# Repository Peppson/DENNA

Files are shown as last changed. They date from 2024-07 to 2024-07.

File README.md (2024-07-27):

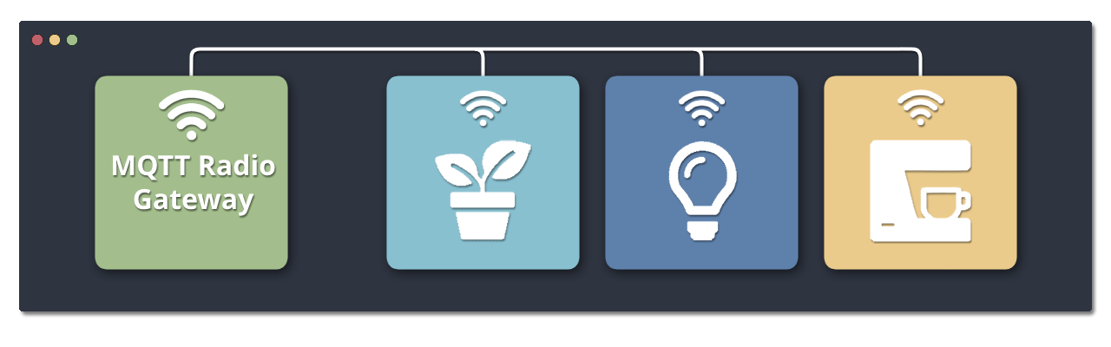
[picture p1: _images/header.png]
flow_diagram


# radio-nodes

Solar/Battery/USB powered wireless "smarthome" modules, based on the Attiny824 microcontroller.  
Serves as the end-node of [MQTT-radio-gateway](https://github.com/Peppson/MQTT-radio-gateway).   
Written in C++ with PlatformIO.  

&nbsp;
## Project Overview
- Each node is easily configurable to perform various tasks, such as watering plants,  
turn on the coffeemaker, opening blinds, relaying sensor data, etc. 

- Power consumption was the main concern when designing this.   
Nodes consumes ∼`2mA` @ 3.3V in active listening mode, and as low as ∼`3uA` @ 3.3V while deepsleeping!  
Making it possible to power some nodes indefinitely from a small solarpanel.  
Measured and optimized using [Power Profiler Kit II](https://www.nordicsemi.com/Products/Development-hardware/Power-Profiler-Kit-2).  

- This project was primarily made for personal ***"needs"***. But it is open for use by anyone who finds it beneficial.  
Every ***node*** has it's own directory inside `src` with it's own enviroment, selected from `platformio.ini`.

&nbsp;
## Hardware and PCB  
Made a compact PCB integrating a [TP4056](https://www.amazon.com/TP4056/s?k=TP4056) Li-ion/LiPo battery charger, an [nRF24L01+](https://www.amazon.com/s?k=nRF24L01%2B&crid=1VM0GXMUG7ISX&sprefix=nrf24l01%2B%2Caps%2C145&ref=nb_sb_noss_1) radio,   
and the [Attiny824](https://www.mouser.se/ProductDetail/Microchip-Technology/ATTINY824-SSF?qs=pUKx8fyJudA6%2F%2FVSNIlI1w%3D%3D) AVR microcontroller.  

More images in: [📂 _images/](./_images/)  
KiCad files: [📂 _KiCad/](./_KiCad/)  

<details>
<summary>
    Schematic
</summary>  

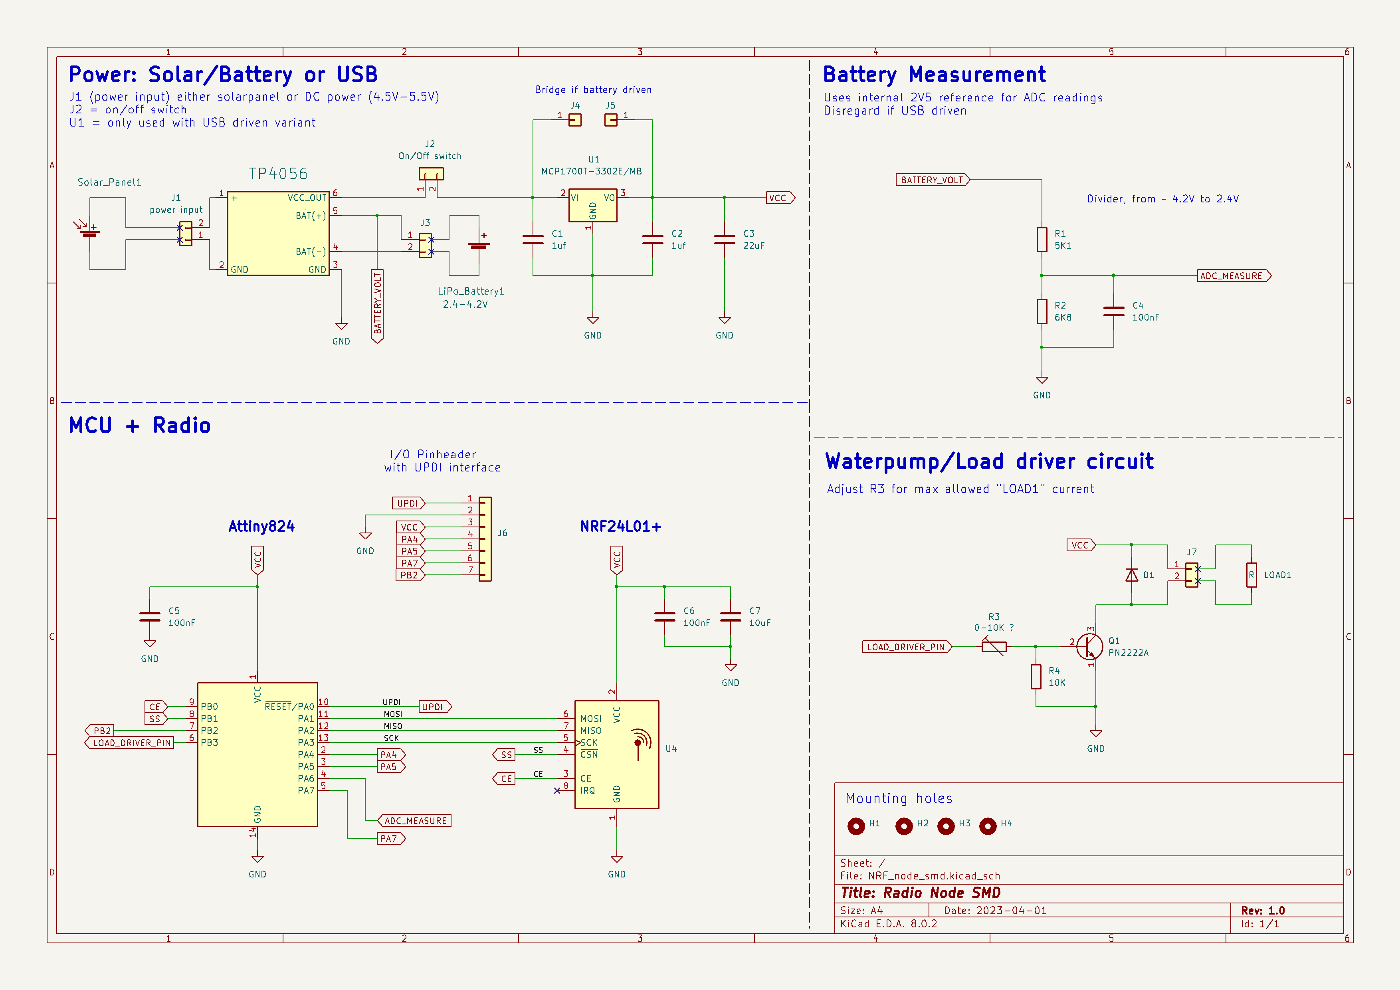
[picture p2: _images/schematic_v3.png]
schematic
  
</details>

<details>
<summary>
    PCB layout 
</summary>     
    
> 2-layer PCB, dimensions 42mm x 31mm.  
> The PCB has 3 sections, configurable based on the node.
> - ***BAT or USB:*** Battery or USB/5V driven.  
> - ***LOAD:*** Components for the "load driver circuit".  

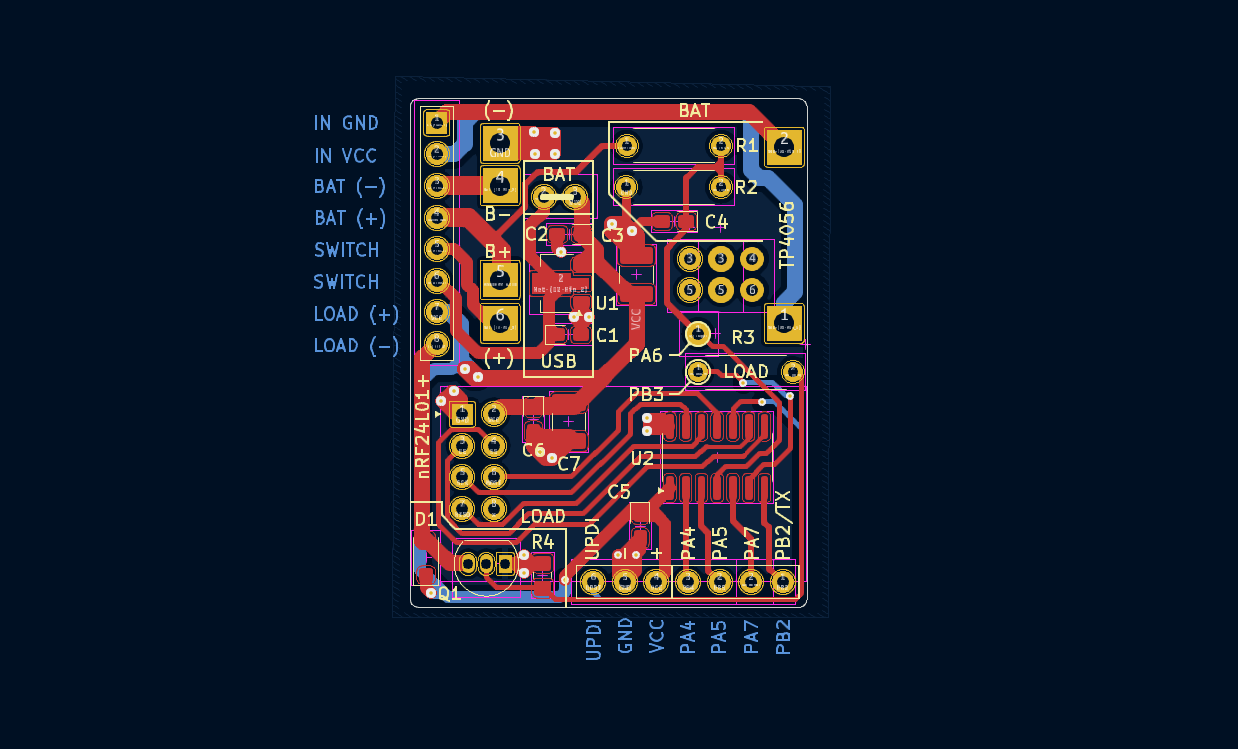
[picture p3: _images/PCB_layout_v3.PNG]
PCB_layout
  
</details>  

<details>
<summary>
    Power consumption in active mode 
</summary>  

> In active mode, the node toggles its radio `on` for 50ms and `off` for 950ms to minimize power usage,    
> halting the CPU between pulses.  
>
> Resulting in an average power draw of ∼2mA @ 3.3V.  

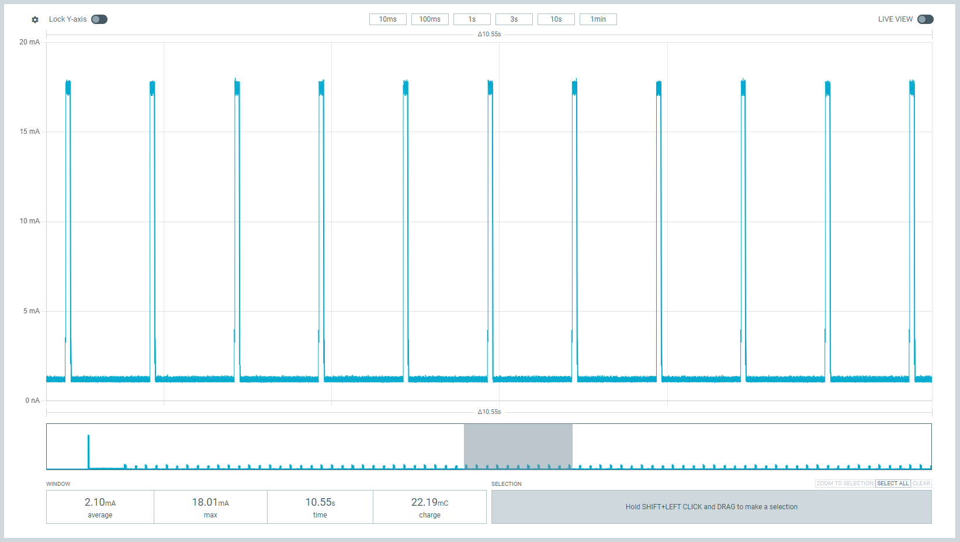
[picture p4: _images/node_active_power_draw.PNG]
  
</details>

<details>
<summary>
    Programming
</summary>  

The ATtiny 2-series MCUs have [UPDI](https://onlinedocs.microchip.com/pr/GUID-F626284A-58F0-4C25-A6F3-0EA5054F3E2B-en-US-6/index.html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) interface. Which makes it possible to program with only 1 data pin!  
You can see the UPDI pins at the bottom of the PCB. 

I created a simple DIY programmer using an Arduino Nano, to help with uploading firmware.   
More details here [UPDI programmer](https://github.com/Peppson/simple-UPDI-programmer).
</details>

### PCB
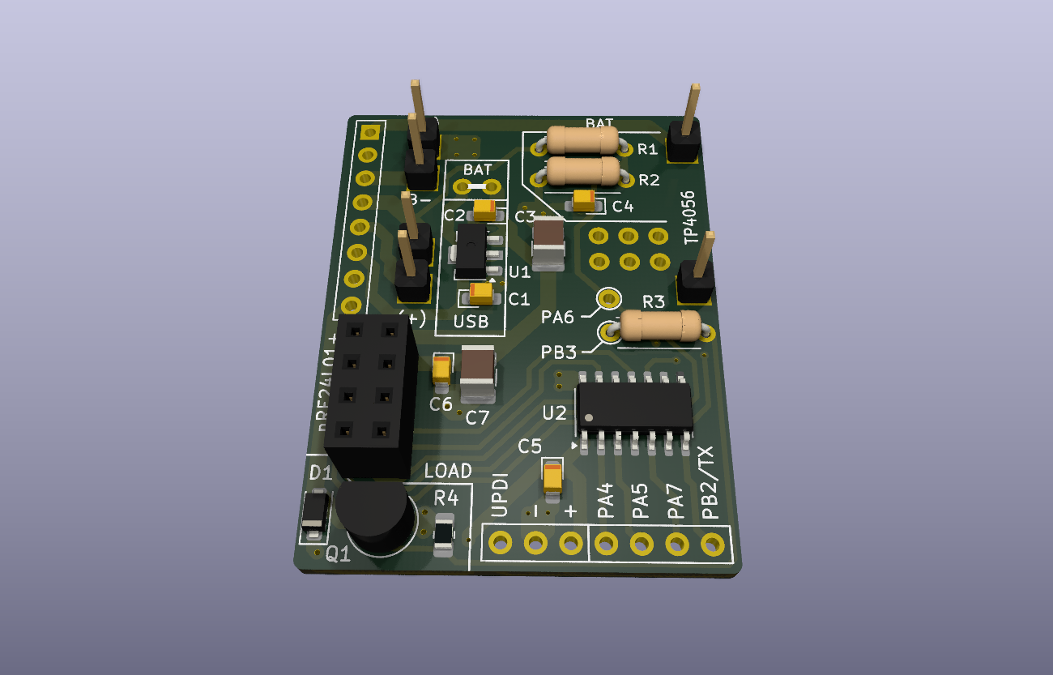
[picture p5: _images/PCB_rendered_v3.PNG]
hardware
    

### Hardware
> With and without the TP4056 and nRF24L01+ modules. Dimensions 42mm x 31mm.  
> The picture shows a battery/solar-powered node.

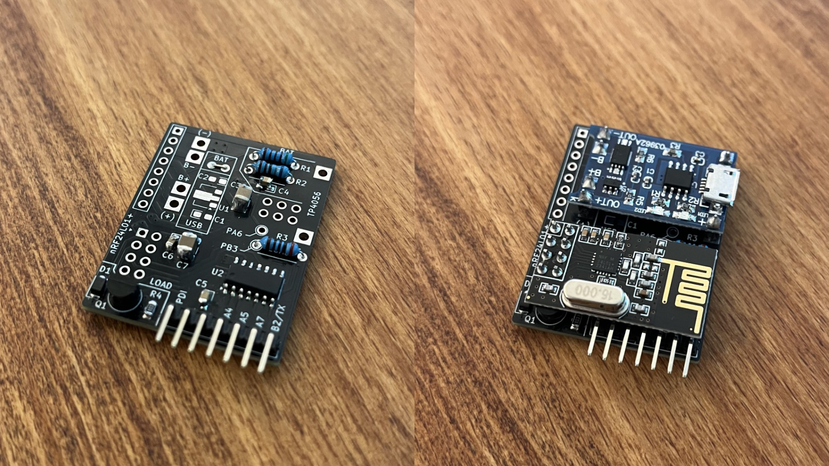
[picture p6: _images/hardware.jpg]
  

&nbsp;
## Nodes 
<details open>
<summary>
    Nodes 1-10: Self watering plants  
</summary>

Uses a 3-5V waterpump and DIY capacative fluid-level sensor.  See link below.  
[Liquid Level Sensing Using Capacitive-to-Digital Converters](https://www.analog.com/en/analog-dialogue/articles/liquid-level-sensing-using-cdcs.html)  

The solar-powered variant uses the TP4056 to charge a Li-ion/LiPo battery.  
While the USB variant skips that step and plugs directly into 5V (with 3.3V LDO onboard).  

#### Node 1 water sensor linearity:    

> Sensor (ADC) reading vs water level in %. 

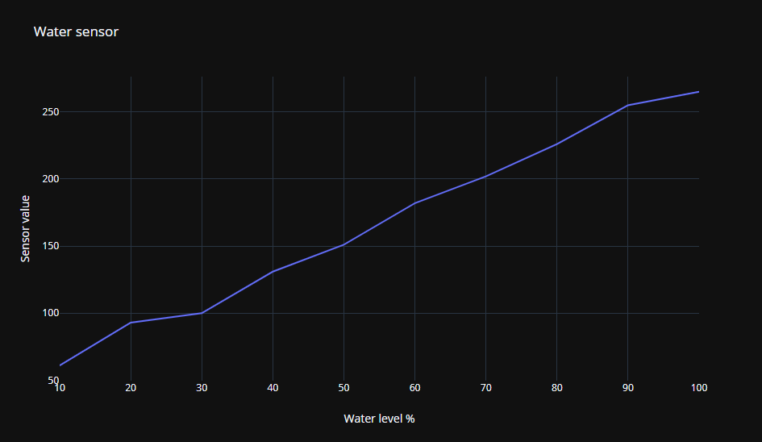
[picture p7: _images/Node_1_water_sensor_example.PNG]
water sensor


#### Node 1 hardware:  

> Most of the self-watering plant nodes have the hardware inside a plastic enclosure,   
> which I just hide behind the pots.  
> However, for node 1, I placed all electronics underneath for a pretty decent look.   

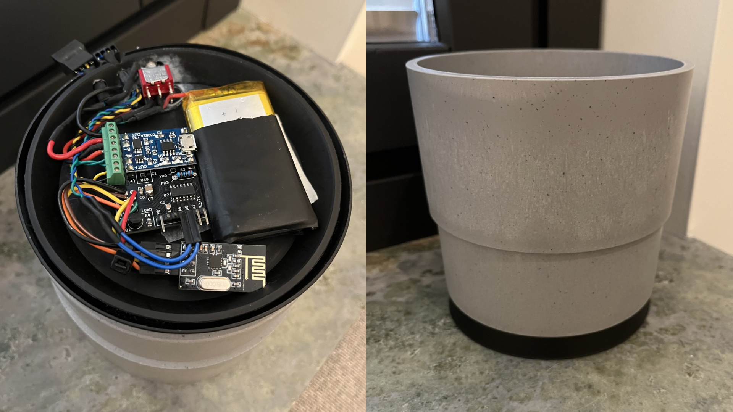
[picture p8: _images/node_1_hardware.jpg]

&nbsp;  

</details>

<details>
    <summary>
        Node 11: Mocca Master controller
    </summary>

Uses a SG90 servo mounted internally to toggle the `On/Off` button,   
and a hall-effect current sensor, to get the current state.
  
> "Looks pretty neat when the button toggles all by itself :)"   

</details>

&nbsp;

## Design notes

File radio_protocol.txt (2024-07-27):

----- Self Watering Flowerpots [1-10] -----
RX: 
    - from_who          = From who
    - to_who            = To who
    - state             = Run waterpump? 
    - data_0            = Run waterpump for how long
    - data_1            = Unused
    - data_2            = 0xFFFD = deepsleep | 0xFFFE = resend message | 0xFFFF = reboot | Current time (hhmm)
TX:
    - from_who          = From who
    - to_who            = To who
    - state             = Unused 
    - data_0            = Water level
    - data_1            = Battery charge (if battery driven)
    - data_2            = Unused / 0xFFFF = request current time

----- MoccaMaster [11] -----
RX: 
    - from_who          = From who
    - to_who            = To who
    - state             = Turn on coffeemachine? 
    - data_0            = Unused
    - data_1            = Unused
    - data_2            = 0xFFFD = deepsleep | 0xFFFE = resend message | 0xFFFF = reboot | Current time (hhmm)
TX:
    - from_who          = From who
    - to_who            = To who
    - state             = Current state of coffemachine 
    - data_0            = Number of coffees made (EEPROM)
    - data_1            = Unused
    - data_2            = Unused / 0xFFFF = request current time

...

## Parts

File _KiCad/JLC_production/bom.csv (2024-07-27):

Designator | Footprint | Quantity | Value | LCSC Part #
C1, C2 | CP_EIA-2012-15_AVX-P_Pad1.30x1.05mm_HandSolder | 2 | 1uf
C3 | 1210 | 1 | 22uF
C4, C5, C6 | CP_EIA-2012-15_AVX-P_Pad1.30x1.05mm_HandSolder | 3 | 100nF
C7 | 1210 | 1 | 10uF
D1 | D_SOD-123F | 1 | D
J6 | PinHeader_1x06_P2.54mm_Vertical | 1 | Conn_01x06
Q1 | TO-92_Inline | 1 | TO-92_Inline
R1 | R_Axial_DIN0207_L6.3mm_D2.5mm_P7.62mm_Horizontal | 1 | 5.1K
R2 | R_Axial_DIN0207_L6.3mm_D2.5mm_P7.62mm_Horizontal | 1 | 6.8K
R4 | 0805 | 1 | 10K
R8 | R_Axial_DIN0207_L6.3mm_D2.5mm_P7.62mm_Horizontal | 1 | 0-10K ?
TP4056 | TP4056-18650 | 1 | ~
U1 | SOT-89-3 | 1 | MCP1700T-3302E/MB
U2 | SOIC-14_3.9x8.7mm_P1.27mm | 1 | ATtiny84A-P
nRF24L01+ | nRF24L01_Breakout | 1 | NRF24L01_Breakout

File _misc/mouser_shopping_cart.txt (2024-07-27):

 
https://www.mouser.se/ProjectManager/ProjectDetail.aspx?AccessID=e2948668ba
Access ID: e2948668ba

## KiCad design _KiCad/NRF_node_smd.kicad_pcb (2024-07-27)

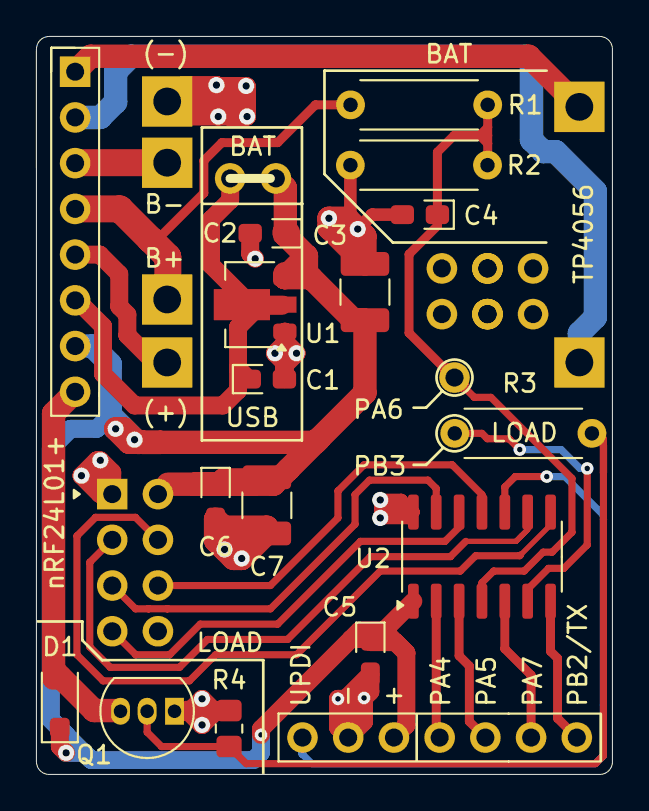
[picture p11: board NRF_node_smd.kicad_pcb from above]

Board: 2 copper layers, 32.0 x 41.0 mm, 18 parts (0 on the bottom side), 16 nets.

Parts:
C1, C2: 1uf; CP_EIA-2012-15_AVX-P_Pad1.30x1.05mm_HandSolder
C3: 22uF; C_1210_3225Metric_Pad1.33x2.70mm_HandSolder
C4, C5, C6: 100nF; CP_EIA-2012-15_AVX-P_Pad1.30x1.05mm_HandSolder
C7: 10uF; C_1210_3225Metric_Pad1.33x2.70mm_HandSolder
D1: D; D_SOD-123F
J6: Conn_01x06; PinHeader_1x06_P2.54mm_Vertical
Q1: TO-92_Inline
R1: 5.1K; R_Axial_DIN0207_L6.3mm_D2.5mm_P7.62mm_Horizontal
R2: 6.8K; R_Axial_DIN0207_L6.3mm_D2.5mm_P7.62mm_Horizontal
R4: 10K; R_0805_2012Metric_Pad1.20x1.40mm_HandSolder
R8: 0-10K ?; R_Axial_DIN0207_L6.3mm_D2.5mm_P7.62mm_Horizontal
TP4056: TP4056-18650
U1: MCP1700T-3302E/MB; SOT-89-3
U2: ATtiny84A-P; SOIC-14_3.9x8.7mm_P1.27mm
nRF24L01+: NRF24L01_Breakout; nRF24L01_Breakout

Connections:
/CE: U2.9 (PB0), nRF24L01+.3 (CE)
/MISO: U2.12 (PA2), nRF24L01+.7 (MISO)
/MOSI: U2.11 (PA1), nRF24L01+.6 (MOSI)
/SCK: U2.13 (PA3), nRF24L01+.5 (SCK)
/SS: U2.8 (PB1), nRF24L01+.4 (~CSN)
ADC_MEASURE: C4.1, R1.2, R2.2, U2.4 (PA6)
BATTERY_VOLT: R1.1, TP4056.5 (BAT(+))
GND: C1.2, C2.2, C3.2, C4.2, C5.2, C6.2, C7.2, J6.5, Q1.1, R2.1, R4.2, TP4056.3 (GND), U1.1 (GND), U2.14 (GND), nRF24L01+.1 (GND)
LOAD_DRIVER_PIN: R8.1, U2.6 (PB3)
unnamed: D1.2 (A), Q1.3
unnamed: C1.1, U1.2 (VI)
unnamed: Q1.2, R4.1, R8.2
PB4: J6.3, U2.2 (PA4)
PB5: J6.2, U2.3 (PA5)
UPDI: J6.6, U2.10 (~RESET/PA0)
VCC: C2.1, C3.1, C5.1, C6.1, C7.1, D1.1 (K), J6.4, U1.3 (VO), U2.1 (VCC), nRF24L01+.2 (VCC)

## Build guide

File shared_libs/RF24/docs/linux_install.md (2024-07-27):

# Linux Installation

@tableofcontents

<!-- markdownlint-disable MD031 -->
Generic Linux devices are supported via SPIDEV, MRAA, RPi native via BCM2835, or using LittleWire.

@note The SPIDEV option should work with most Linux systems supporting spi userspace device.

@warning These install instructions are beginning to age because they were designed with the assumption that
the arm-linux-gnueabihf-g\*\* compilers were available and default for the system. If you have problems
using the manual install instructions (especially on a 64-bit OS), please try the
[instructions using CMake](md_docs_using_cmake.html).

@note Since wiringPi is no longer maintained or distributed (as of RPi OS 11 bullseye),
pigpio is now required for using the radio's IRQ pin. This applies to RPi, SPIDEV, and pigpio drivers. The MRAA driver may provide its own IRQ implementation. Remember that the RPi OS lite variant does not ship with pigpio installed.

## Automated Install

**Designed & Tested on RPi** - Defaults to SPIDEV on devices supporting it

1. Install prerequisites if there are any (pigpio, MRAA, LittleWire libraries, setup SPI device etc)
2. Download the install.sh file from [http://tmrh20.github.io/RF24Installer/RPi/install.sh](http://tmrh20.github.io/RF24Installer/RPi/install.sh)
   ```shell
   wget http://tmrh20.github.io/RF24Installer/RPi/install.sh
   ```
3. Make it executable
   ```shell
   chmod +x install.sh
   ```
4. Run it and choose your options
   ```shell
   ./install.sh
   ```
5. Run an example from one of the libraries
   ```shell
   cd rf24libs/RF24/examples_linux
   ```
   Edit the gettingstarted example, to set your pin configuration
   ```shell
   nano gettingstarted.cpp
   make
   sudo ./gettingstarted
   ```

## Manual Install

1. Install prerequisites if there are any (pigpio, MRAA, LittleWire libraries, setup SPI device etc)
   @note See the [MRAA](http://iotdk.intel.com/docs/master/mraa/index.html) documentation for more info on installing MRAA
2. Make a directory to contain the RF24 and possibly RF24Network lib and enter it
   ```shell
   mkdir ~/rf24libs
   cd ~/rf24libs
   ```
3. Clone the RF24 repo
   ```shell
   git clone https://github.com/tmrh20/RF24.git RF24
   ```
4. Change to the new RF24 directory
   ```shell
   cd RF24
   ```
5. Configure build environment using
   ```shell
   ./configure
   ```
   script. It auto detectes device and build environment.

   For overriding autodetections, use command-line switches, see
   ```shell
   ./configure --help
   ```
   for description.
6. Build the library, and run an example file
   ```shell
   make
   sudo make install
   ```
   ```shell
   cd examples_linux
   ```
   Edit the gettingstarted example, to set your pin configuration
   ```shell
   ano gettingstarted.cpp
   make
   sudo ./gettingstarted
   ```

### Build using SPIDEV

1. Make sure that spi device support is enabled and /dev/spidev\<a\>.\<b\> is present
2. Manual Install using SPIDEV:
   ```shell
   ./configure --driver=SPIDEV
   make
   sudo make install
   ```
3. See the gettingstarted example for an example of pin configuration

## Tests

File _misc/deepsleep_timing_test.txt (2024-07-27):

15 min 
18:53:49.706 > start
19:08:49.817 > stop

2h
19:22:44.489 > start
21:22:48.503 > stop

12h TODO

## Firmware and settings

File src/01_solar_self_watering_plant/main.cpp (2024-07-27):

#include "../global_config.h"
#include "node_program.h"
#include "rf24_radio.h"
#include "hardware.h"
#include "water_system.h"
#include "utility.h"

Hardware hardware(true);
RF24Radio radio;
WaterSystem water_system(selected_node::WATER_SENSOR_MIN_VALUE, selected_node::WATER_SENSOR_MAX_VALUE);


#if CALIBRATION
void setup() { Hardware::begin(&radio); util::calibration(); }
void loop() {}
#else


void setup() {
    hardware.begin(&radio, true);
    radio.begin();
    selected_node::send_sensor_data(radio, true);
}


void loop() {
    WDT_FEED();

    // Save power by toggling radio transceiver on/off
    radio.power_up();

    // Listen for new radio message
    if (radio.wait_for_message(RF24_ON_TIME)) {
        selected_node::handle_RX_message(radio);
    }

    // Powerdown 
    radio.power_down();
    hardware.lightsleep(RF24_OFF_TIME);

    // Time to send data to master?
    uint32_t cur_time = millis();
    if (cur_time > hardware.next_update_time) {
        selected_node::send_sensor_data(radio, false);
    }

    // Time to sleep?
    if (cur_time > hardware.deepsleep_time) {
        hardware.deepsleep(selected_node::SLEEP_DURATION_SECONDS);
    } 
   
}
#endif   

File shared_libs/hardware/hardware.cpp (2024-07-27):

#include "hardware.h"
#include "utility.h"
#include "../shared_libs/rf24_radio/rf24_radio.h"


// Members
uint32_t Hardware::deepsleep_time = 0; 
uint32_t Hardware::next_update_time = 0;
RF24Radio* Hardware::_radio_ptr;
volatile bool _lightsleep_wakeup;


// RTC Interrupt handler. Wakes up the CPU periodically while deepsleeping
// Only way to timekeep while deepsleeping
ISR (RTC_CNT_vect) {
    RTC.INTFLAGS |= RTC_OVF_bm;
    _lightsleep_wakeup = true;
}


// Helper
constexpr uint32_t convert_hhmm_to_seconds(const uint32_t& value) {
    static_assert(selected_node::SLEEP_AT_THIS_TIME >= 0 && 
        selected_node::SLEEP_AT_THIS_TIME <= 2400, "Node time must follow \"hhmm\" format");

    uint32_t hour = value / 100;  
    uint32_t minute = value % 100; 

    return (hour * 60 * 60) + (minute * 60);
}


void Hardware::begin(RF24Radio* radio_ptr, const bool ADC_ref_2V5) {
    #if USB_SERIAL_ENABLED
        init_TX_serial(); 
    #endif

    // Helps with uploading if CPU is stuck "RSP_ILLEGAL_MCU_STATE"
    delay(2000);
    #if DEV_RECOVERY_DELAY
        delay(5000);
    #endif

    // Enable Watchdog at max interval ≈ 4s 
    WDT_ENABLE();
    WDT_FEED();

    // Set internal 2.5V reference for ADC
    if (ADC_ref_2V5) {
        ADC0.CTRLC = TIMEBASE_1US | INTERNAL2V5;
    }

    // Save pointer to radio
    _radio_ptr = radio_ptr; 

    // Disable unused peripherals
    ADC0.CTRLA &= ~ADC_ENABLE_bm;   // ADC 
    TWI0.CTRLA &= ~TWI_ENABLE_bm;   // I2C
    CCL.CTRLA &= ~CCL_ENABLE_bm;    // CCL
}


void Hardware::set_default_pin_states(bool is_battery_Driven) {
    pinMode(PIN_POWER_IO, OUTPUT);
    digitalWrite(PIN_POWER_IO, LOW);
    pinMode(PIN_UPDI, INPUT_PULLUP);
    pinMode(PIN_TX_SERAIL, INPUT_PULLUP);
    pinMode(PIN_PA4, INPUT_PULLUP);
    pinMode(PIN_PA5, INPUT_PULLUP);
    pinMode(PIN_PA7, INPUT_PULLUP);

    is_battery_Driven ? pinMode(PIN_PA6, INPUT) : pinMode(PIN_PA6, INPUT_PULLUP); // Battery ADC pin
}


void Hardware::disable_all_pins() {
    // PIN_POWER_IO has to remain active to hold state low
    for (size_t i = 0; i < 12; i++) {
        if (i == PIN_POWER_IO) { continue; }
        pinMode(i, INPUT_PULLUP);
    }
}


void Hardware::init_TX_serial() {
    Serial.begin(SERIAL_BAUD_RATE, (SERIAL_8N1 | SERIAL_TX_ONLY));
    while (!Serial) { }
    log("\n-- Node %i --\n", RF24_THIS_ADDRESS);

    #if USB_SERIAL_ENABLED
        //#error "Makes sure nothing is connected on RX pin" // Even with TX only...
    #endif
}


void Hardware::restart_device() { 
    _radio_ptr->power_down();
    
    // Wait for Watchdog to reset board
    _PROTECTED_WRITE(WDT.CTRLA, WDT_PERIOD_4KCLK_gc);
    while (1) { delay(1); } 
}


void Hardware::deepsleep(uint32_t sleep_duration_s) {
    const uint16_t sleep_limit = sleep_duration_s / SLEEP_RTC_INTERVAL_SECONDS;
    volatile uint16_t sleep_counter = 0;

    disable_all_peripherals();
    WDT_DISABLE();

    //
    // Enable periodic RTC interrupts to allow the CPU to wake up from sleep
    // Average time between interrupts = 64.299 seconds
    // Continue to sleep until (sleep_counter * 64.299) > SLEEP_DURATION_SECONDS
    // Average current = 3uA while sleeping
    // 
  
    RTC.PER = 0xFFFF;                               // Set period: 1-65535 (0XFFFF longest possible interval)
    RTC.CLKSEL = RTC_CLKSEL_INT1K_gc;               // Set 1kHz internal clock as source
    RTC.INTCTRL |= RTC_OVF_bm;                      // Interrupt when period overflows
    RTC.CTRLA = RTC_RTCEN_bm | RTC_RUNSTDBY_bm;     // Enable + active in SLEEP_MODE_STANDBY

    // ZZZZzzzzZzzzzZzz
    set_sleep_mode(SLEEP_MODE_STANDBY);
    sleep_enable();
    sleep_cpu();

    // Continue to sleep for sleep_duration_s
    while (sleep_counter < sleep_limit) {
        sleep_counter++;    
        RTC.CNT = 0; // Reset timer
        sleep_cpu();
    }
        
    // Wake up
    sleep_disable();
    restart_device(); // Full reset
}


void Hardware::lightsleep(uint16_t sleep_duration_ms) {
    WDT_FEED();
    if (sleep_duration_ms >= 35*1000) { // Dont allow longer sleep than the watchdog timeout
        sleep_duration_ms = 35*1000; 
    }

    // Similar behavior as deepsleep()
    RTC.PER = sleep_duration_ms;            // Set period: 1-65535 
    RTC.CLKSEL = RTC_CLKSEL_INT1K_gc;       // Set 1kHz internal clock as source
    RTC.INTCTRL |= RTC_OVF_bm;              // Interrupt when period overflows
    RTC.CTRLA = RTC_RTCEN_bm;               // Enable
    RTC.CNT = 0;                            // Reset RTC

    // ZZZZzzzzZzzzzZzz
    _lightsleep_wakeup = false; 
    set_sleep_mode(SLEEP_MODE_IDLE);
    sleep_enable();
    sleep_cpu();

    // Continue to lightsleep for sleep_duration_ms
    // TCB 0 and 1 interrupts alot, only wake up from RTC interrupt 
    while (!_lightsleep_wakeup) {    
        WDT_FEED();
        sleep_cpu();
    }

    // Wake up
    RTC.INTCTRL &= ~RTC_OVF_bm; // Disable RTC interrupt
    sleep_disable();
    WDT_FEED();
}
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

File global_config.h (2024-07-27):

#pragma once 
#include <Arduino.h>
#include <avr/io.h>
#include <avr/sleep.h>
#include <avr/wdt.h>
#include <avr/interrupt.h>
#include <stdint.h>


// Dev
#define USB_SERIAL_ENABLED 0                                // Serial TX 
#define DEV_RECOVERY_DELAY 1                                // Used for easier code uploading
#define WATCHDOG_ENABLED 1                                  // Onboard Watchdog
#define DEBUG_LOOP_ENABLED 0                                // Enter debug_loop()
#define ADC_CAL_ENABLED 0                                   // Battery ADC calibration
#define PUMP_CAL_ENABLED 0                                  // Water pump calibration
#define SERVO_CAL_ENABLED 0                                 // Servo calibration

// NRF24L01+ radio
constexpr uint8_t RF24_THIS_ADDRESS = NODE_ID;              // Radio address (env var from platformio.ini)
constexpr uint8_t RF24_MASTER_ADDRESS = 0;                  // Address of master (0)
constexpr uint16_t RF24_ON_TIME = 50;                       // Active
constexpr uint16_t RF24_OFF_TIME = 950;                     // Sleeping                                  
constexpr uint8_t RF24_CHANNEL = 120;                       // Channel 1-126 (check with RF24/examples/scanner/scanner.ino) (120)
constexpr uint8_t RF24_PIPE = 1;                            // Pipe address (1)
#define RF24_OUTPUT (RF24_PA_MAX)                           // Output level: RF24_PA_MIN, RF24_PA_LOW, RF24_PA_HIGH, RF24_PA_MAX, ERROR
#define RF24_DATARATE (RF24_250KBPS)                        // Datarate: RF24_2MBPS, RF24_1MBPS, RF24_250KBPS

// Misc
constexpr float SLEEP_RTC_INTERVAL_SECONDS = 64.299;        // Calibrated Average time between RTC interrupts while deepsleeping (s)
constexpr uint8_t WATER_PUMP_RUNTIME_MAX = 10;              // Maximum time the waterpump is allowed to run (s) if a flowerpot node
constexpr uint32_t SERIAL_BAUD_RATE = 9600;                 // TX serial rate

// Message commands
enum MsgCommand : uint16_t {
    REBOOT = 0xFFFF,
    RESEND = 0xFFFE,
    SLEEP = 0xFFFD
};

/*
-------------------------- ATtiny824 Pinout --------------------------                                   

                         VCC  1|o   |14 GND                        
             PWM/ADC --- PA4  2|    |13 PA3 --- RF24 SCK          
             PWM/ADC --- PA5  3|    |12 PA2 --- RF24 MISO  
                 ADC --- PA6  4|    |11 PA1 --- RF24 MOSI           
                 ADC --- PA7  5|    |10 PA0 --- UPDI programming          
           Power I/O --- PB3  6|    |9  PB0 --- RF24 CE          
       TX Serial out --- PB2  7|    |8  PB1 --- RF24 CSN  

----------------------------------------------------------------------
*/
#define PIN_CE                  PIN_PB0         // Nrf24l01 Ce pin
#define PIN_CSN                 PIN_PB1         // Nrf24l01 CSN pin
#define PIN_UPDI                PIN_PB0         // UPDI programming
#define PIN_POWER_IO            PIN_PB3         // Controls the "power circuit"
#define PIN_TX_SERAIL           PIN_PB2         // Serial out   
#define PIN_WATER_SENSOR_OUT    PIN_PA4         // Diy capacitive sensor out    (4)
#define PIN_WATER_SENSOR_IN     PIN_PA5         // Diy capacitive sensor in     (5)                                                              

// Watchdog
#if WATCHDOG_ENABLED
    #define WDT_FEED() __asm__ __volatile__ ("wdr") 
    #define WDT_ENABLE() _PROTECTED_WRITE(WDT.CTRLA, WDT_PERIOD_4KCLK_gc)
    #define WDT_DISABLE() wdt_disable()
#else
    #define WDT_FEED()
    #define WDT_ENABLE()
    #define WDT_DISABLE()
#endif

// Logging
#if USB_SERIAL_ENABLED
    #define log(...) Serial.printf(__VA_ARGS__)
    #define STOP log("\n-----  STOP  ----- \n"); while (1) { WDT_FEED(); delay(1000); }
#else
    #define log(...)
    #define STOP
#endif

// Include selected node's "node_config.h" into global space (a bit hacky?)
#if NODE_ID == 1
    #include "src/01_solar_self_watering_plant/node_config.h"
#elif NODE_ID == 2
    #include "src/02_solar_self_watering_plant/node_config.h"
#elif NODE_ID == 6
    #include "src/06_USB_self_watering_plant/node_config.h"
#elif NODE_ID == 7
    #include "src/07_USB_self_watering_plant/node_config.h"
#elif NODE_ID == 11
    #include "src/11_moccamaster/node_config.h"
#elif NODE_ID == 255 // Debug
    #include "src/255_debug/node_config.h"
#else
    #error "Unknown NODE_ID, check platformio.ini"
#endif

// CALIBRATION true if any of the calibration macros are set
#if DEBUG_LOOP_ENABLED || ADC_CAL_ENABLED || PUMP_CAL_ENABLED || SERVO_CAL_ENABLED
    #define CALIBRATION true
#else 
    #define CALIBRATION false
#endif

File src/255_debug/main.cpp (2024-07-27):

#include "../global_config.h"
#include "node_program.h"
#include "rf24_radio.h"
#include "hardware.h"
#include "water_system.h"
#include "utility.h"
#include "capacitor_lite/capacitor_lite.h"

//RF24Radio radio;
Hardware hardware(false);
WaterSystem water_system(selected_node::WATER_SENSOR_MIN_VALUE, selected_node::WATER_SENSOR_MAX_VALUE);


void setup() {
    //hardware.begin(&radio);
    hardware.init_TX_serial();
    delay(2000);



    ADC0.CTRLA |= ADC_ENABLE_bm;
    ADC0.CTRLC = TIMEBASE_1US | DEFAULT; 
    CapacitorLite water_sensor(PIN_WATER_SENSOR_OUT, PIN_WATER_SENSOR_IN);

    while (1) {
        uint32_t sum = 0;
        for (size_t i = 0; i < 100; i++) {
            sum += water_sensor.measure();
        }
        log("%i\n", sum / 100); 
        delay(500);
    }
    STOP


    while (1) {
        log("%i\n", water_sensor.measure());
        delay(250);
    }
    STOP


    /* ADC0.CTRLC = TIMEBASE_1US | DEFAULT;
    uint8_t adcRef = ADC0.CTRLC & ADC_REFSEL_gm;
    if (adcRef == VDD) {
        log("1\n");
    } else if (adcRef == EXTERNAL) {
        log("2\n");
    } else if (adcRef == INTERNAL1V024) {
        log("3\n");
    } else if (adcRef == INTERNAL2V048) {
        log("4\n");
    } else if (adcRef == INTERNAL2V5) {
        log("5\n");
    } else if (adcRef == INTERNAL4V096) {
        log("6\n");
    }
    STOP */


    /* while (1) {
        uint16_t level = 0;
        for (size_t i = 0; i < 1000; i++) {
            level = analogRead(PIN_PA6);
        }
        log("%i\n", level);
    } */


    // disaable ADC = 
    // measuring = 

    

    log("GOOOOO!\n");
    while (1) {
        ADC0.CTRLA |= ADC_ENABLE_bm; // enable 

        uint32_t sum = 0;
        for (size_t i = 0; i < 100; i++) {
            uint16_t level = analogRead(PIN_PA6); 
            sum += level;
            delay(1);
        }
        sum = sum / 100;
        log("%i\n", sum);

        ADC0.CTRLA &= ~ADC_ENABLE_bm; // disable
        delay(5000);
   }


    


    digitalWrite(PIN_PA7, LOW);
    uint16_t val = 0;
    while (1) {
        val = hardware.get_remaining_battery_charge();
        log("%i\n", val);
        delay(400);
    }
    
}


void loop() {
    hardware.set_default_pin_states();
} 
